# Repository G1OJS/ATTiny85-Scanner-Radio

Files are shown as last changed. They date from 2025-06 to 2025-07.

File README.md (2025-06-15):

# ATTiny85-Scanner-Radio
Airband Scanner on an ATTiny85 using Si5351 and not much else!

This is a work in progress, but feel free to copy stuff and play with it. The code uses my own minimised Si5351 library which you can find [here](https://github.com/G1OJS/G1OJS_Tiny_Si5351_CLK0). There's also a schematic and a model of the MC1350 that I made from the schematic in the datasheet.

https://github.com/user-attachments/assets/3ad3e072-7772-4eb5-b2a6-2552d3ed8b62

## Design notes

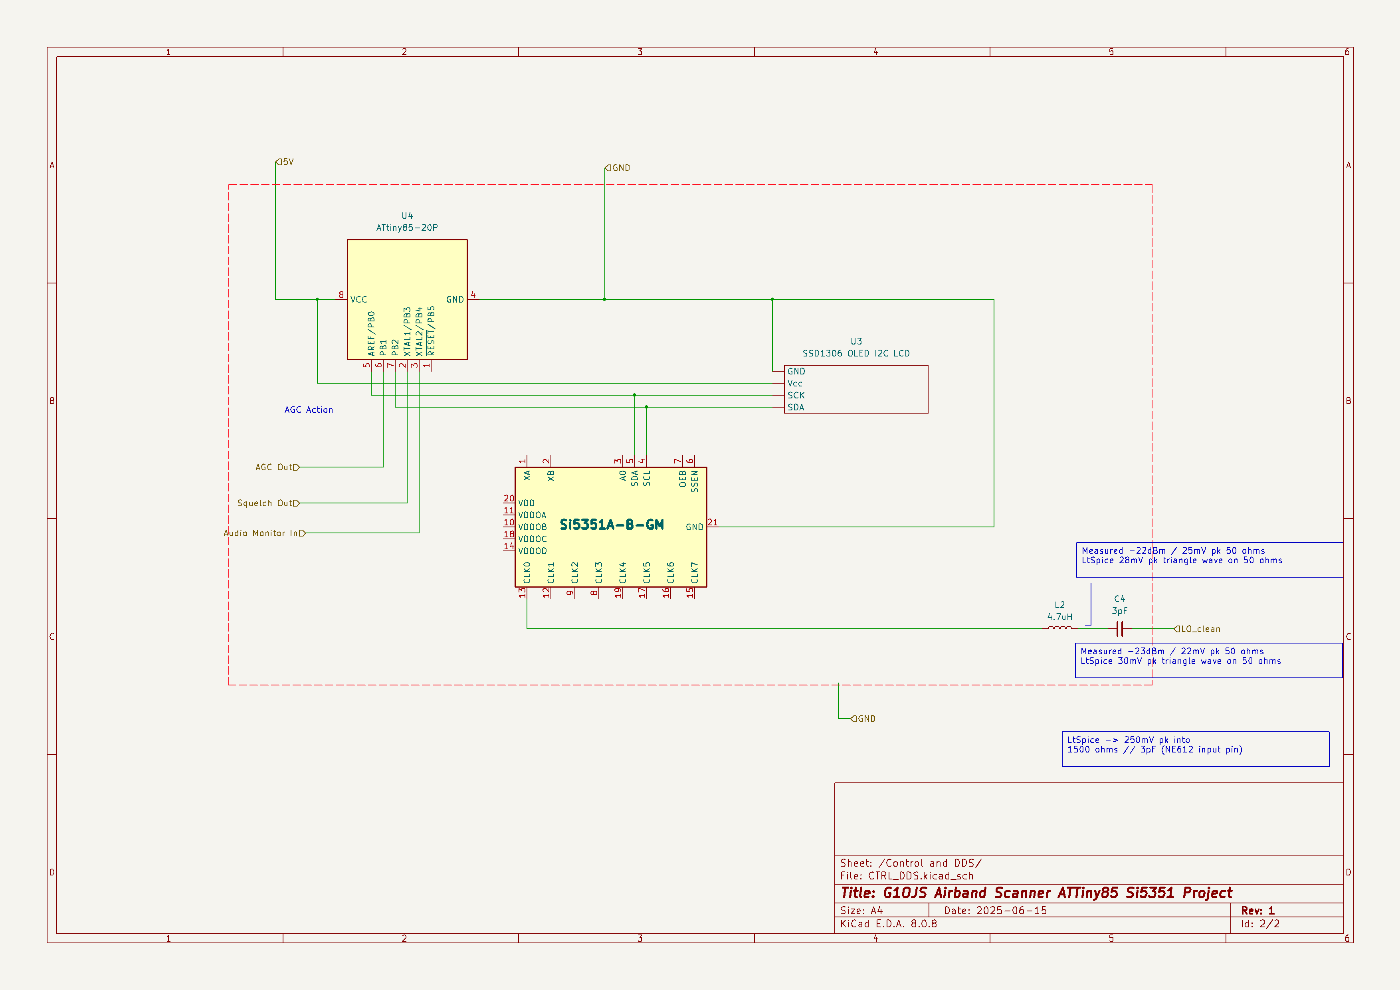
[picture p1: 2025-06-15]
Schematics/Airband Scanner Control and DDS.kicad.png

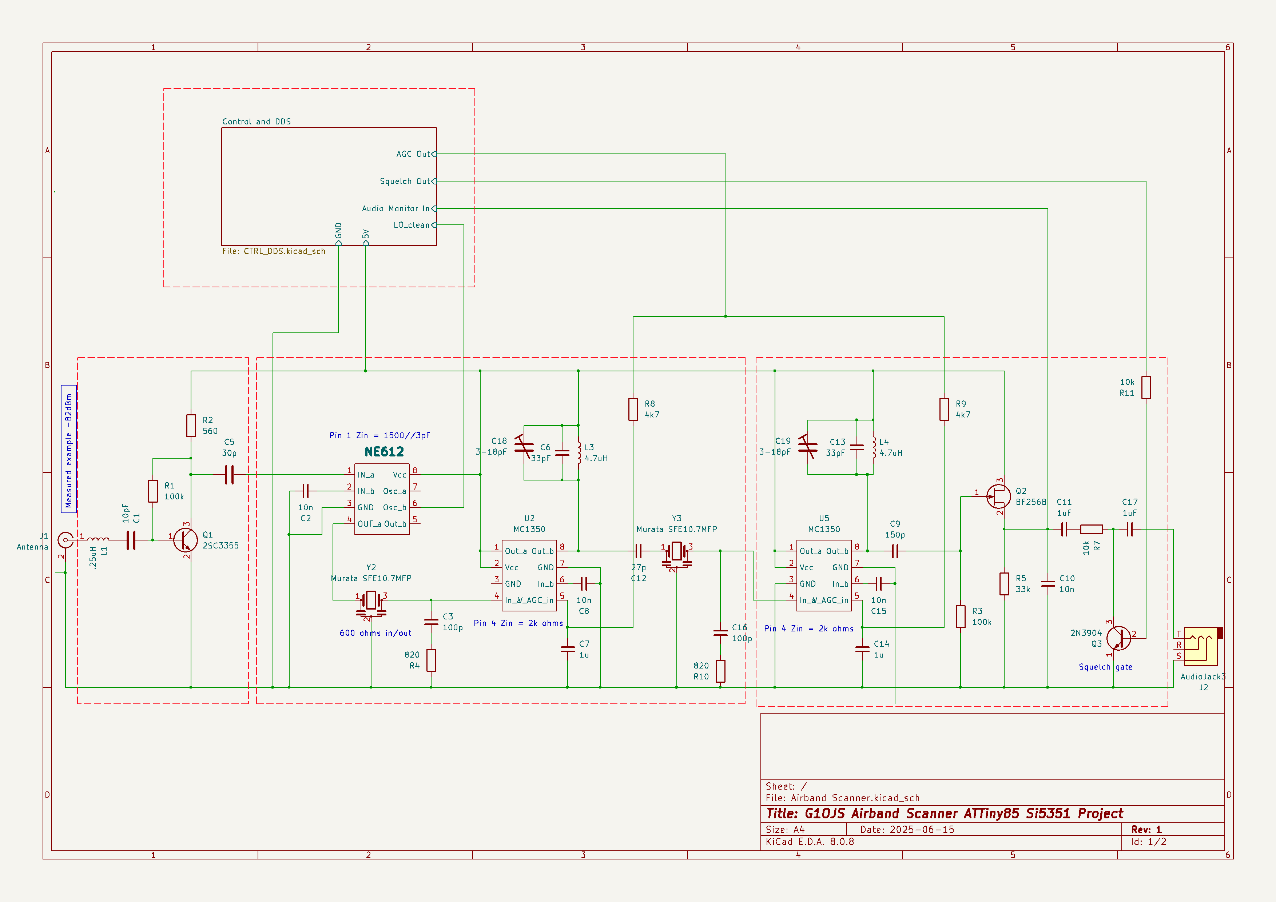
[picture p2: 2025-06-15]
Schematics/Airband Scanner.kicad.png

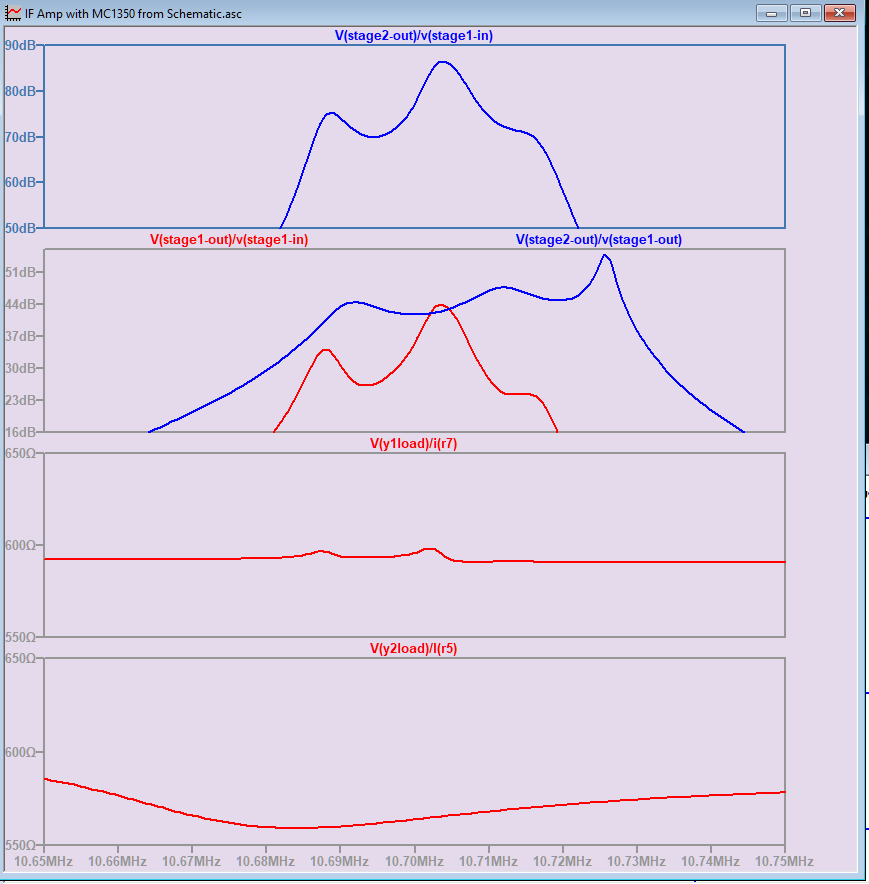
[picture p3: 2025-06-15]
LtSpice/LtSpice_IF_AMP_Model.PNG

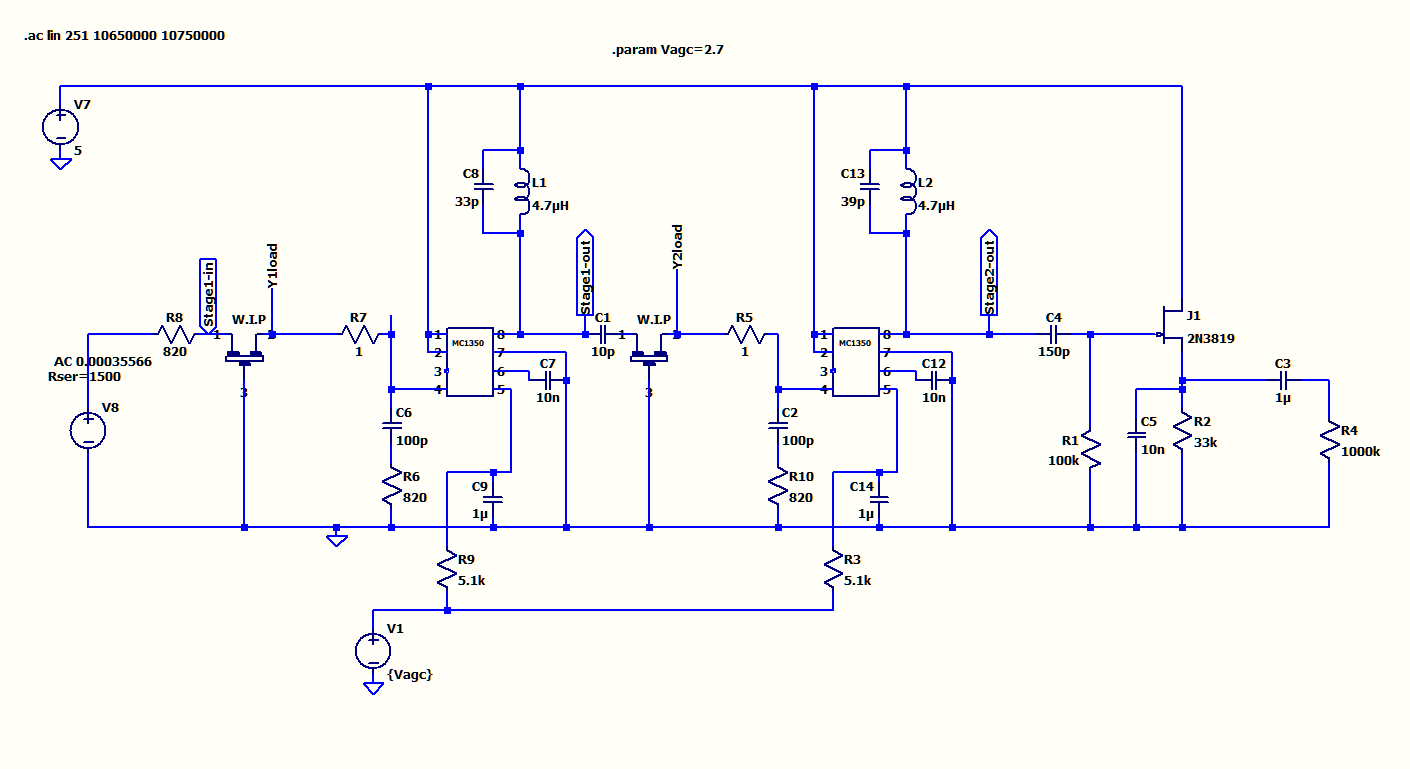
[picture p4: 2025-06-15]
LtSpice/LtSpice_IF_Amp_Detector.PNG

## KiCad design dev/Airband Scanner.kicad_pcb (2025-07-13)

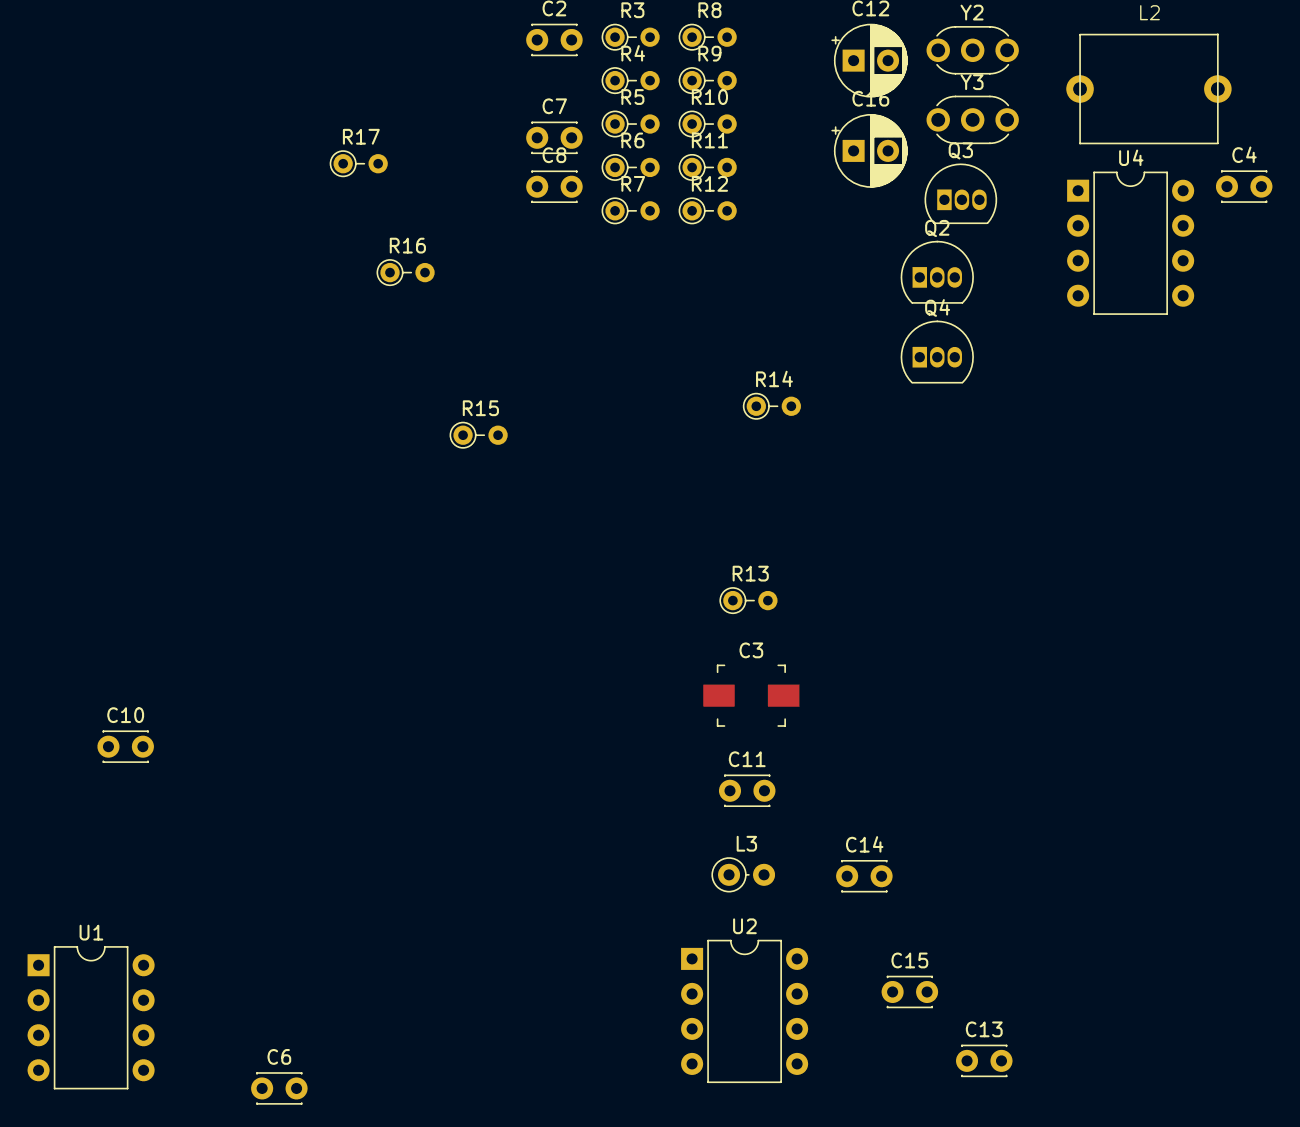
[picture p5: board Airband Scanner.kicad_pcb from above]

Board: 2 copper layers, 38 parts (0 on the bottom side), 23 nets, no tracks yet.

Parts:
C2: 10nF; C_Disc_D3.0mm_W2.0mm_P2.50mm
C3: 3-18pF; C_Trimmer_Murata_TZB4-A
C4: 3pF; C_Disc_D3.0mm_W2.0mm_P2.50mm
C6, C7: 1n; C_Disc_D3.0mm_W2.0mm_P2.50mm
C8: 47p; C_Disc_D3.0mm_W2.0mm_P2.50mm
C10: 330p; C_Disc_D3.0mm_W2.0mm_P2.50mm
C11: 33pF; C_Disc_D3.0mm_W2.0mm_P2.50mm
C12: 1u; CP_Radial_D5.0mm_P2.50mm
C13, C15: 10n; C_Disc_D3.0mm_W2.0mm_P2.50mm
C14: 150p; C_Disc_D3.0mm_W2.0mm_P2.50mm
C16: 1uF; CP_Radial_D5.0mm_P2.50mm
L2: 4.7uH; Inductor_Axial_L10.0mm_D7.9mm_P10.0mm_Horizontal
L3: 4.7uH; L_Axial_L5.3mm_D2.2mm_P2.54mm_Vertical_Vishay_IM-1
Q2, Q4: 2N3904; TO-92_Inline
Q3: BF256B; TO-92L_Inline
R3: 6k8; R_Axial_DIN0204_L3.6mm_D1.6mm_P2.54mm_Vertical
R4: 2k2; R_Axial_DIN0204_L3.6mm_D1.6mm_P2.54mm_Vertical
R5: 330; R_Axial_DIN0204_L3.6mm_D1.6mm_P2.54mm_Vertical
R6: 150; R_Axial_DIN0204_L3.6mm_D1.6mm_P2.54mm_Vertical
R7: 4k7; R_Axial_DIN0204_L3.6mm_D1.6mm_P2.54mm_Vertical
R8: 100k; R_Axial_DIN0204_L3.6mm_D1.6mm_P2.54mm_Vertical
R9: 1k5; R_Axial_DIN0204_L3.6mm_D1.6mm_P2.54mm_Vertical
R10: 33k; R_Axial_DIN0204_L3.6mm_D1.6mm_P2.54mm_Vertical
R11: 1k; R_Axial_DIN0204_L3.6mm_D1.6mm_P2.54mm_Vertical
R12: 270; R_Axial_DIN0204_L3.6mm_D1.6mm_P2.54mm_Vertical
R13: 470k; R_Axial_DIN0204_L3.6mm_D1.6mm_P2.54mm_Vertical
R14: 10k; R_Axial_DIN0204_L3.6mm_D1.6mm_P2.54mm_Vertical
R15: 560; R_Axial_DIN0204_L3.6mm_D1.6mm_P2.54mm_Vertical
R16: 600; R_Axial_DIN0204_L3.6mm_D1.6mm_P2.54mm_Vertical
R17: 820; R_Axial_DIN0204_L3.6mm_D1.6mm_P2.54mm_Vertical
U1: NE612; DIP-8_W7.62mm
U2: MC1350; DIP-8_W7.62mm
U4: ATtiny85-20P; DIP-8_W7.62mm
Y2, Y3: Resonator; Resonator_Murata_CSTLSxxxX-3Pin_W5.5mm_H3.0mm

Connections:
/Control and DDS/5V: C3.1, C11.1, L3.1, Q3.3 (D), R3.1, R5.1, R13.1, R16.1, U1.8 (Vcc), U2.1 (Out_a), U2.2 (Vcc), U4.8 (VCC)
/Control and DDS/GND: C2.1, C10.2, C12.2, C13.2, C15.2, Q4.1 (E), R4.2, R6.2, R8.2, R10.2, R17.2, U1.3 (GND), U2.7 (GND), U4.4 (GND), Y2.2, Y3.2
/Control and DDS/LO_clean: C4.1, U1.6 (Osc_b)
unnamed: C4.2, L2.1
unnamed: C6.2, R17.1
unnamed: C7.1, R15.1
unnamed: C8.1, R9.1
unnamed: C16.2, R11.1
unnamed: C8.2, Q2.2 (B), R3.2, R4.1
unnamed: Q2.3 (C), R5.2, R12.2
unnamed: C10.1, Q2.1 (E), R6.1
unnamed: C14.2, Q3.1 (G), R8.1
unnamed: C15.1, C16.1, Q3.2 (S), R10.1, R14.2
unnamed: C7.2, Q4.2 (B)
unnamed: Q4.3 (C), R16.2, Y3.1
unnamed: R12.1, Y2.1
unnamed: R15.2, Y2.3
unnamed: C2.2, U1.2 (IN_b)
unnamed: R9.2, U1.4 (OUT_a)
unnamed: C6.1, U2.4 (In_a), Y3.3
unnamed: C13.1, U2.6 (In_b)
unnamed: C3.2, C11.2, C14.1, L3.2, R13.2, U2.8 (Out_b)
unnamed: C12.1, R7.2, U2.5 (V_AGC_in)

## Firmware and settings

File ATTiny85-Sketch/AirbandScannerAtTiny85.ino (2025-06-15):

#include <G1OJS_Tiny_Si5351_CLK0.h>


#include <Wire.h>
#include <SSD1306Ascii.h>
#include <SSD1306AsciiWire.h>
#include "Arduino.h"

#define AGC_OUT PB1     // ATtiny85 physical pin 6
#define SQUELCH_OUT PB3 // ATtiny85 physical pin 2
#define AUDIO_IN A2    // ATtiny85 physical pin 3
// SDA is PB0 ATtiny85 physical pin 5
// SCL is PB2 ATtiny85 physical pin 7

// =================
// proxy for ms() as timer0 will be running at 4kHz not 500Hz
//==================
unsigned long ms(){return millis()/8;} 

// =================
// I2C comms initialiser that waits until initialised
//==================
struct {
  void init(){
      Wire.begin();
      do{
        Wire.beginTransmission(0x3C);  // Known I2C address (e.g., OLED)
        delay(10);
      } while (Wire.endTransmission() != 0);
  }
} i2c;

// =================
// OLED
//==================
struct {
  #define OLED_I2C_ADDRESS 0x3C
  SSD1306AsciiWire OLED;

  void init(){

   // Wire.setClock(400000);
    Wire.begin();
    do{
      Wire.beginTransmission(0x3C);  // Known I2C address (e.g., OLED)
      delay(10);
    } while (Wire.endTransmission() != 0);
    OLED.begin(&Adafruit128x64, OLED_I2C_ADDRESS);
    OLED.clear();

  	OLED.setFont(Arial14);
  	OLED.set2X();
  	OLED.clear();
    OLED.println("G1OJS");
    OLED.println("ATTiny85");
    delay(500);
  	OLED.clear();
    OLED.println("Airband");
    OLED.println("Scanner");
    delay(500);
  	OLED.clear();
  }

  void showStatusChar(char* symbol){
    OLED.setCursor(100,0);
    OLED.print(symbol);
  }

  void showChannel(byte channel) 
    {
    OLED.setCursor(0, 0);
    ultoa((unsigned long)channel, buf, 10);
    OLED.print(buf);
  }

  void showFreq(unsigned long freq_Hz) 
    {
    OLED.setCursor(0, 4);
    ultoa(freq_Hz/1000, buf, 10);
    OLED.print(buf);
  }

  void clearFreq(){
    
  }

  private:
    char buf[6];

} DISP;

G1OJS_Tiny_Si5351_CLK0 DDS;

// =================
// AUDIO MONITOR
//==================
struct {
  int currentAmplitude=0;

  init(){
    analogReference(DEFAULT); 
    pinMode(AUDIO_IN, INPUT);
    currentAmplitude=0;
  }

  void updateCurrentAmplitude(){
    int currSigLevel=analogRead(AUDIO_IN); 
    currentAmplitude=abs(currSigLevel-lastSigLevel);
    lastSigLevel=currSigLevel;
  }
  
  private:
    int lastSigLevel=0;

} preSquelchAudioMonitor;

// =================
// SQUELCH
//==================
struct {
  enum statusValues {OPEN=0, CLOSED=1};
  statusValues status = CLOSED;

  void init() {
    pinMode(SQUELCH_OUT, OUTPUT);
    close();
  }

  void open() {
    status = OPEN;
    digitalWrite(SQUELCH_OUT, LOW);
    DISP.showStatusChar("O");
  }

  void close() {
    status = CLOSED;
    digitalWrite(SQUELCH_OUT, HIGH);
    DISP.showStatusChar("C");
  }

  void implement() {
    if (preSquelchAudioMonitor.currentAmplitude > threshold) {
      if (status == CLOSED) {
        open();
      }
      lastAboveThreshold_ms = ms();
    } else {
      if ((ms() - lastAboveThreshold_ms) > tail_ms) {
        close();
      }
    }
  }

  private:
    const int tail_ms   = 1000;
    const int threshold = 20;
    unsigned long lastAboveThreshold_ms;

} squelch;

// =================
// SCANNER
//==================
struct {
  #define channelStep 25000
  #define nChannels 5
  unsigned long channels_Hz[nChannels]= {128602650, 127825000, 132846700, 135050000, 129425000};
 // boolean lockout[nChannels] = {1,0,0,0,0};
  boolean lockout[nChannels] = {0,1,1,1,1};
  int channel;
  enum scannermodes{SCAN, SEARCH};
  scannermodes mode;

  void init(){
    channel = 0;
    mode = SCAN;
  }

  void spinnerNext() {
    const char spinner[] = {'|', '/', '-', '\\'};
    DISP.showStatusChar(spinner[channel++ % 4]);
    }

  void setTestFreq(){
    setRxFreq(128602650UL);
    DISP.showChannel(0);
    DISP.showFreq(128602650UL); 
  }

  void findNextBusyMemory(){
    if (squelch.status == squelch.OPEN) return;
    do{channel = (channel + 1) % nChannels;} while (lockout[channel]);

    DISP.showChannel(channel);
    if(channels_Hz[channel] != lastFreq) {
      setRxFreq(channels_Hz[channel]);
      DISP.showFreq(channels_Hz[channel]); 
      lastFreq = channels_Hz[channel];
    }
  }

  void findNextBusyFrequency(){
    searchFreq += channelStep;
    if (searchFreq > 136000000ULL) {
      init();
    }

    setRxFreq(searchFreq);
    spinnerNext();
    if (squelch.status == squelch.OPEN) {
      // do something on display to show searching & search speed, and/or channel found
      DISP.showFreq(searchFreq); 
      delay(10);
      // check frequency and add etc
    }
  }

  void startSearch(){
    searchFreq = 118000000ULL;
    mode = SEARCH;
  }

  void setRxFreq(unsigned long freq_Hz){
    #define IF_kHz 10707
    DDS.set_freq_Hz((uint32_t)freq_Hz + (uint32_t)IF_kHz*1000);
  }

  void scan(){
    if (mode == SCAN) {findNextBusyMemory();}
    if (mode == SEARCH) {findNextBusyFrequency();}
  }

  private:
    unsigned long lastFreq;
    unsigned long searchFreq;


} scanner;

// =================
// AGC LOOP
//==================
struct {

  void init() {
    // Configure PB1 (OC1B) as output
    DDRB |= _BV(PB1); // PB1 = physical pin 6

    // Setup Timer1 for 8-bit Fast PWM on OC1B (PB1)
    // Set both PB0 (pin5) and PB1 (pin6) to 4kHz non-inverted PWM
    // see https://www.gammon.com.au/timers
    TCCR0A = bit (WGM00) | bit (WGM01) | bit (COM0A1);  // Timer 0, A side: fast PWM, clear OC0A on compare
    TCCR0B = bit (CS01);                                // Timer 0, A side: fast PWM, top at 0xFF, prescale x8 (4kHz)
    TCCR0A |= bit (COM0B1);                             // Timer 0, B side: clear OC0B on compare
  }

  void implement(){
    int currAmp=preSquelchAudioMonitor.currentAmplitude;
    if (currAmp > thresholdUpper) {level += 2*(level < maxOutputLevel);}
    if (currAmp < thresholdLower) {level -= 1*(level > minOutputLevel);}
    OCR0B = level;
  }

  private:
    const byte thresholdUpper = 160;
    const byte thresholdLower = 20;
    const byte maxOutputLevel = 250;
    const byte minOutputLevel = 110;
    byte level = minOutputLevel;

} agc;

// =================
// NON-BLOCKING TASK RUNNER
//==================
class regularTask {
public:
  unsigned long last_ms;
  unsigned int  interval_ms;
  void (*callback)();

  regularTask(unsigned int interval, void (*cb)()) {
    interval_ms = interval;
    last_ms = ms();
    callback = cb;
  }

  void runIfDue() {
    unsigned long now = ms();
    if (now - last_ms >= interval_ms) {
      last_ms = now;
      if (callback) callback();
    }
  }
};

// Create tasks to 'runIfDue()' in loop()
regularTask squelchTask(50, []() { squelch.implement(); });
regularTask AGCTask(100,  []() { agc.implement();});
regularTask ScannerTask(50,  []() { scanner.scan();});
regularTask audioMonitorTask(50,  []() {   preSquelchAudioMonitor.updateCurrentAmplitude();});



void setup()
{
  i2c.init();
  DISP.init();
  preSquelchAudioMonitor.init();
  squelch.init();
  agc.init();
  scanner.init();
  //scanner.startSearch();
 // scanner.setTestFreq();
}


void loop() {
  
  squelchTask.runIfDue();
  AGCTask.runIfDue();
  ScannerTask.runIfDue();
  audioMonitorTask.runIfDue();
  
}

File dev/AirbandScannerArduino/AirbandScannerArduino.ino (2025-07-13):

#include <G1OJS_Tiny_Si5351_CLK0.h>
#include <G1OJS_Scanner.h>

#include "Arduino.h"

#include <Wire.h>
#include <SSD1306Ascii.h>
#include <SSD1306AsciiWire.h>


#define LCD_I2C_ADDRESS 0x3C
#define CORRECTION_FACTOR 159000

#define AGC_OUT 10
#define SQUELCH_OUT 8
#define AUDIO_IN A0
// SDA is A4
// SCL is A5

// =================
// NON-BLOCKING TASK RUNNER
//==================
class regularTask {
public:
  unsigned long last_ms;
  byte interval_ms;
  void (*callback)();

  regularTask(byte interval, void (*cb)()) {
    interval_ms = interval;
    last_ms = 0;
    callback = cb;
  }

  void runIfDue() {
    unsigned long now = ms();
    if (now - last_ms >= interval_ms) {
      last_ms = now;
      if (callback) callback();
    }
  }
};

void OutputAGC() {
    AGC.updateAGCLevel();
 //   OCR0B = AGC.AGCLevel;
    analogWrite(AGC_OUT,AGC.AGCLevel);
}

void tickSerial(){
  Serial.print((int)(millis()/1000));
  Serial.print(" ");
}

// Create tasks to 'runIfDue()' in loop()
regularTask squelchTask(50, []() { Squelch.implement(); });
regularTask AGCTask(100,  []() { OutputAGC();});
regularTask ScannerTask(50,  []() { Scanner.scan();});
regularTask audioMonitorTask(50,  []() {  preSquelchAudioMonitor.updateCurrentAmplitude();});


void setup()
{
  Serial.begin(9600);
  Serial.println("Starting setup");
  
  TCCR1B = TCCR1B & B11111000 | B00000001; // set a high (~60kHz) PWM frequency to make filtering to DC easy
  pinMode(AGC_OUT ,OUTPUT);

  
  i2c.init();
  ScannerDisplay.init();
  preSquelchAudioMonitor.init(AUDIO_IN);
  AGC.init();
  Squelch.init(SQUELCH_OUT);
  Scanner.init();
  Scanner.doChannelSurvey();

}

void loop() {
//  squelchTask.runIfDue();
//  AGCTask.runIfDue();
//  ScannerTask.runIfDue();
//  audioMonitorTask.runIfDue();

}

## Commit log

2025-06-14 Initial files mainly for backup
    Some files need completing e.g. KiCad schematic.
    [Airband Scanner.kicad_sch]
2025-06-15 Rename Airband Scanner.kicad.png to Schematics/Airband Scanner.kicad.png
2025-06-15 Update and rename Airband Scanner.kicad_sch to Schematics/Airband Scanner.kicad_sch
    [Airband Scanner.kicad_sch]
2025-06-15 Rename Airband Scanner Control and DDS.kicad.png to Schematics/Airband Scanner Control and DDS.kicad.png
2025-07-13 Add local files
    [Airband Scanner.kicad_pcb, Airband Scanner.kicad_sch, CTRL_DDS.kicad_sch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]
